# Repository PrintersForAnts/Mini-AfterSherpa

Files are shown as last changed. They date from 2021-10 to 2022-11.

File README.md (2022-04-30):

# Mini-AfterSherpa

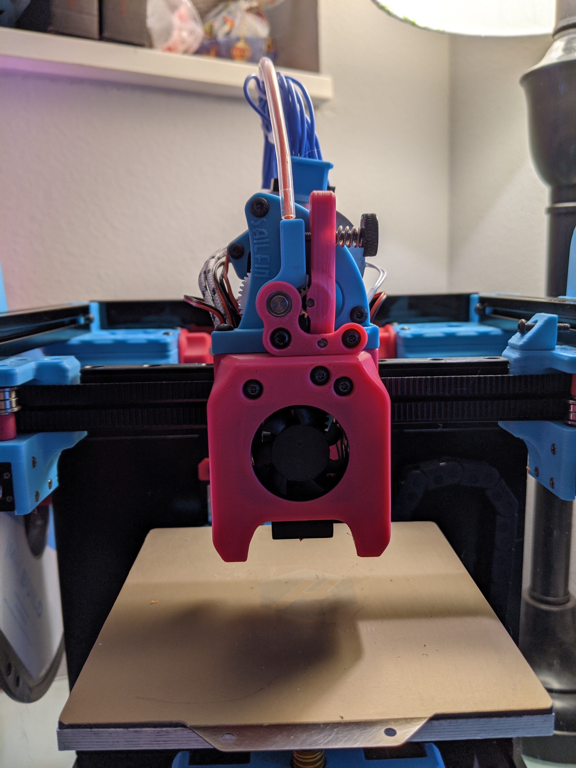
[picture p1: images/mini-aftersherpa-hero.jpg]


The Mini-AfterSherpa is an alternate toolhead for Voron V0.1 and similar printers ([Micron][micronURL], [Flying Zero][fzeroURL], [Salad Fork][saladForkURL], etc) that use the Mini-Afterburner-style X carriage. It offers flexibility and extruder choice with additional convenience.

[micronURL]: https://github.com/hartk1213/micron
[fzeroURL]: https://github.com/zruncho3d/f-zero
[saladForkURL]: https://github.com/YeriWyn/Salad_Fork

## Features

### Direct-drive extruders

With the Mini-AfterSherpa, you can choose from multiple direct-drive extruders.

- [Sherpa Mini](https://github.com/Annex-Engineering/Sherpa_Mini-Extruder)
- [Sherpa Micro](https://github.com/Annex-Engineering/Sherpa_Micro-Extruder) (Via untested adapter)
- [Sailfin](https://github.com/CroXY3D/Sailfin-Extruder)
- [Reverse Pocketwatch V2](STL/Reversed_PocketWatch2/Reversed_Pocketwatch2_Mini_AS_Edition_v0.593.zip), a modified version of the original [Pocketwatch V2](https://github.com/VoronDesign/Pocket-Watch)
- [Orbiter V1.5/V2.0](https://www.thingiverse.com/thing:4725897) (V1.5 supported, V2 TBD)
- [Jetpack](https://github.com/VoronDesign/Jetpack-Extruder) (coming soon, maybe someday)

### Bowden setups

Or, instead, [you can use a Bowden adapter][sherpaBowdenURL] to pair the Mini-AfterSherpa with any standard 1.75mm-filament Bowden extruder, including the [Voron M4][voronM4URL].

[sherpaBowdenURL]: https://github.com/KurioHonoo/Mini-AfterSherpa/tree/main/mods/LED-Bowden-Adapter
[voronM4URL]: https://github.com/VoronDesign/Mobius-Extruder/

### Hotends

- The Phaetus and TriangleLab Dragons and Phaetus Dragonfly BMO [share the same body][dragonflySTL].
- The groove-mount E3D V6 and _Zodiac_ Dragonfly BMO also [both share a main body][groovemountSTL], but you have to print the slide-in mount that goes with your hotend.
- The Slice Engineering Mosquito and Mellow NF Crazy [both share a main body](mosquitoSTL) as well.
- Support is _here_ for Zodiac and Phaetus Dragonfly BM**S**, as well as Revo Micro (and more…)

[dragonflySTL]: STL/Mini_AfterSherpa/Mini_AfterSherpa_Dragon(fly).stl
[groovemountSTL]: STL/Mini_AfterSherpa/Mini_AfterSherpa_Zodiac_BMO_Plus_V6_Body_x1.stl
[mosquitoSTL]: STL/Mini_AfterSherpa/Mini_AfterSherpa_Skeeter_x1.stl
[_insert_Revo Micro here_]
[_insert Revo Voron here_]
[_insert V6_Zodiac_BMO here_]

### Zip tie slots



The Mini-AfterSherpa includes two slots for zip ties to aid in cable management and strain relief. They're much easier to access and route cables through than the zip tie slots on the X carriage (and if you're using an aluminum X carriage like the one from Funssor, then it doesn't even _have_ any zip tie slots!)

## Assembly

### BOM

- 2×: M2.5×8mm BHCS/SHCS (to connect the hotend)
- 2×: M3×5×4mm heatset inserts (to connect the extruder or Bowden adapter)
- 3×: M3×35mm FHCS, BHCS, or SHCS
- 2×: 3010 blower fans (same as Mini-Afterburner)
- 1×: 3007 axial fan (same as Mini-Afterburner)

For Bowden setups:

- 1×: ECAS04 Bowden collet and clip
- 1×: 2mm innner diameter/4mm outer diameter PTFE tubing, 25mm long

### Instructions

1. Install both heatset inserts on the holes far to the sides of the top of the Mini-AfterSherpa.
1. Install fans following the instructions on [page 109 of the V0.1 manual](https://github.com/VoronDesign/Voron-0/raw/Voron0.1/Manuals/Assembly_Manual_0.1.pdf).
1. Install the hotend. 
  - For Dragon or Phaetus Dragonfly BMO, use the M2.5 bolts that came with the hotend. The following diagram will help determine which holes to use for your hotend.
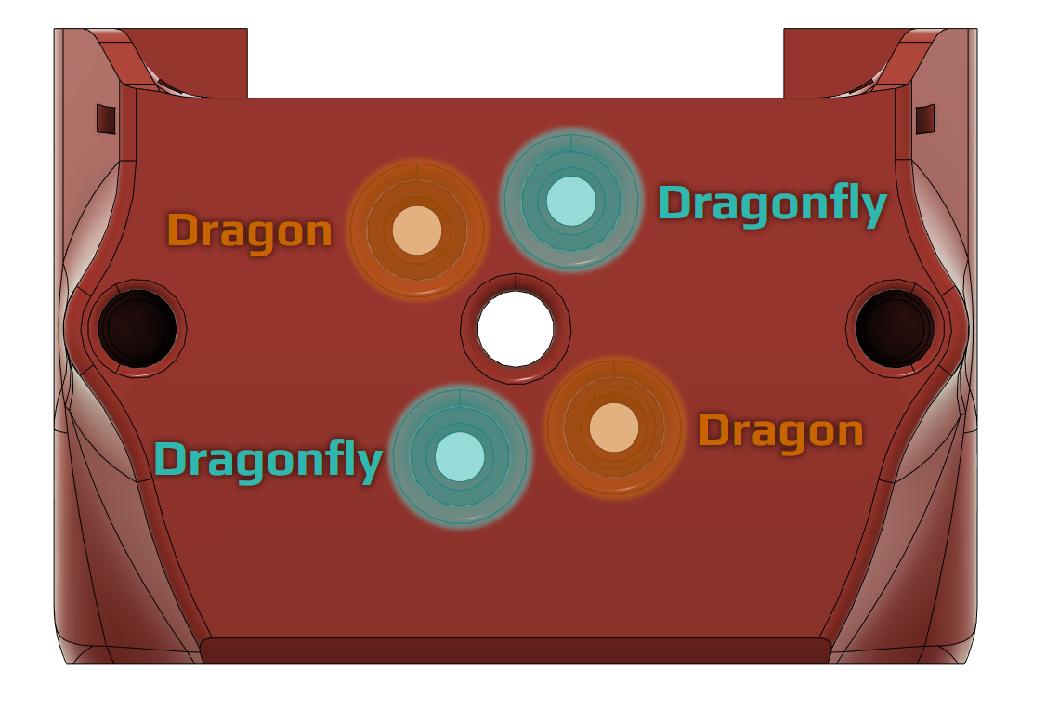
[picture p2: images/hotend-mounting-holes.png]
     
  - For the groove-mount V6 or the Zodiac Dragonfly BMO, slide the groove at the top of the heatsink into the main Mini-AfterSherpa body, then secure it in place by sliding the other mount part in behind the toolhead.
1. Attach the Mini-AfterSherpa to your X carriage with the M3×35mm bolts. Route the hotend wires to either side of the toolhead, and make sure not to crush them when you're tightening the M3 bolts.
1. Use zip ties to secure the wires on the sides of the Mini-AfterSherpa.   
   
1. Install your extruder or Bowden adapter.

## About

Made by [Kyrios](https://github.com/KurioHonoo), based on the [AfterSherpa by smolboi](https://www.thingiverse.com/thing:4977800).

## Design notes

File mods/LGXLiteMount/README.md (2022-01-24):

#LGX Lite Mount (beta) for V0.1 MiniAfterSherpa - Replaces MiniSherpa
MiniASLGXerpaLite.stl

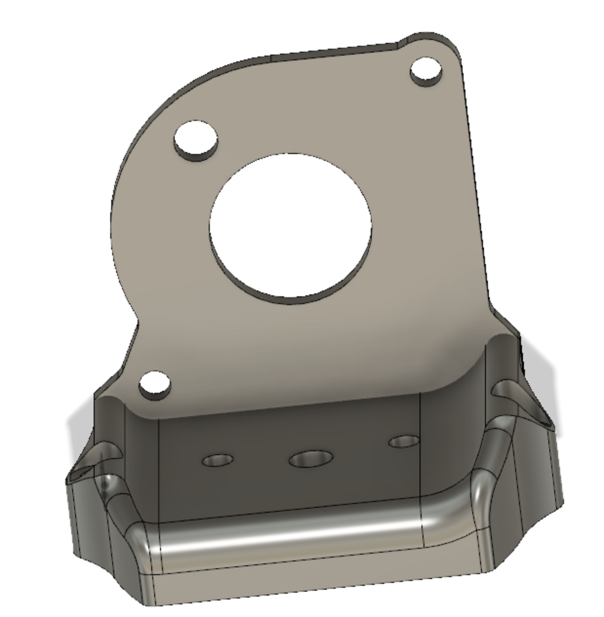
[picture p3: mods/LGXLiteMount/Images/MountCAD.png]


Use 2 x M3x8 from bottom up to secure LGX Lite to mount (Let me know if M3x10 would be better)
Use 2 x M3x12 from top down to secure mount to Mini-AfterSherpa https://github.com/KurioHonoo/Mini-AfterSherpa

Use PTFE tube (the include PTFE from LGX Lite is too short)

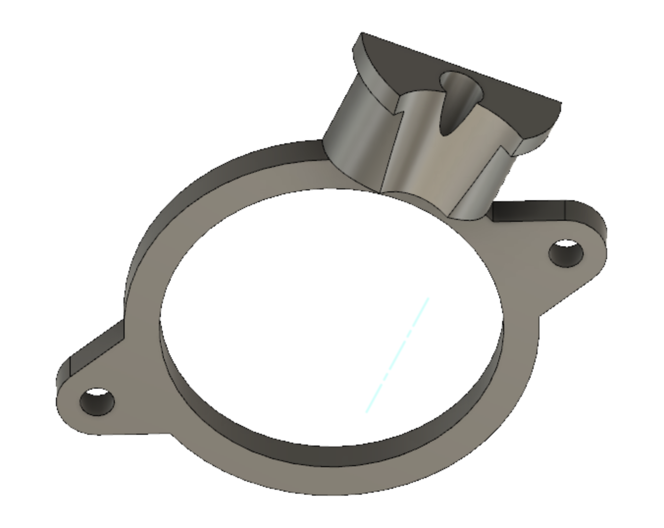
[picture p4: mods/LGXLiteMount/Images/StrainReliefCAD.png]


Strain Relief & Spacers
MiniASLGXerpaLite-StrainRelief.stl
Strain_Relief_Spacers_x2.stl

Use 2 x M3x30 (partially threaded preferred) to replace included M3x25
Optional Use Short piece of PTFE for added relief

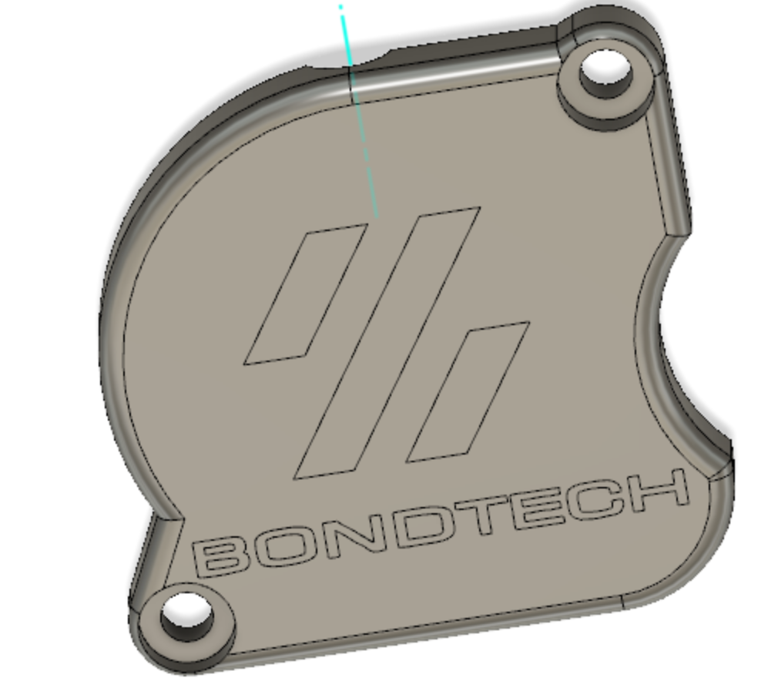
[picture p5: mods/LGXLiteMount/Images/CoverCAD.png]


LGX Lite Cover* - Bondtech requests that the logo be on the cover
MiniASLGXerpaLite-Cover.stl

*Tolerances are NOT exactly like the original cover.  Use at your own risk :D

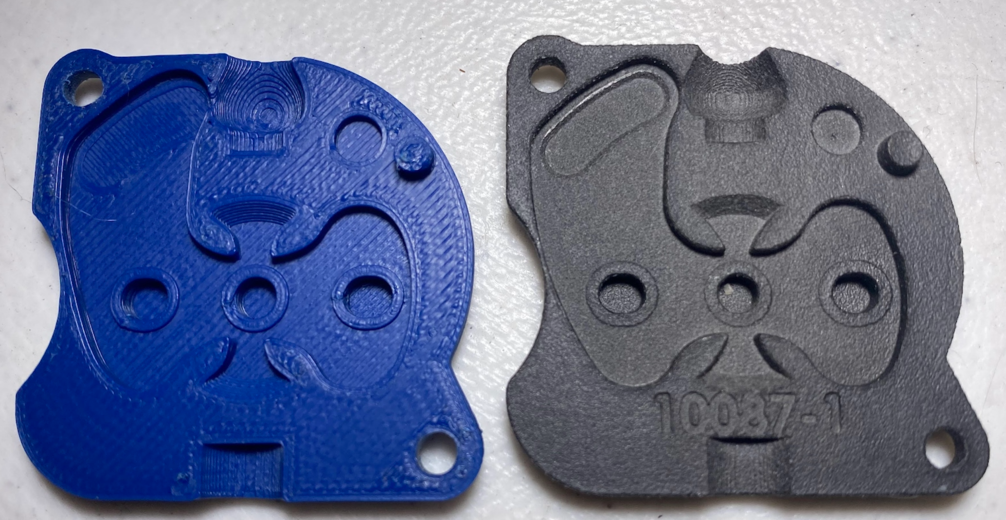
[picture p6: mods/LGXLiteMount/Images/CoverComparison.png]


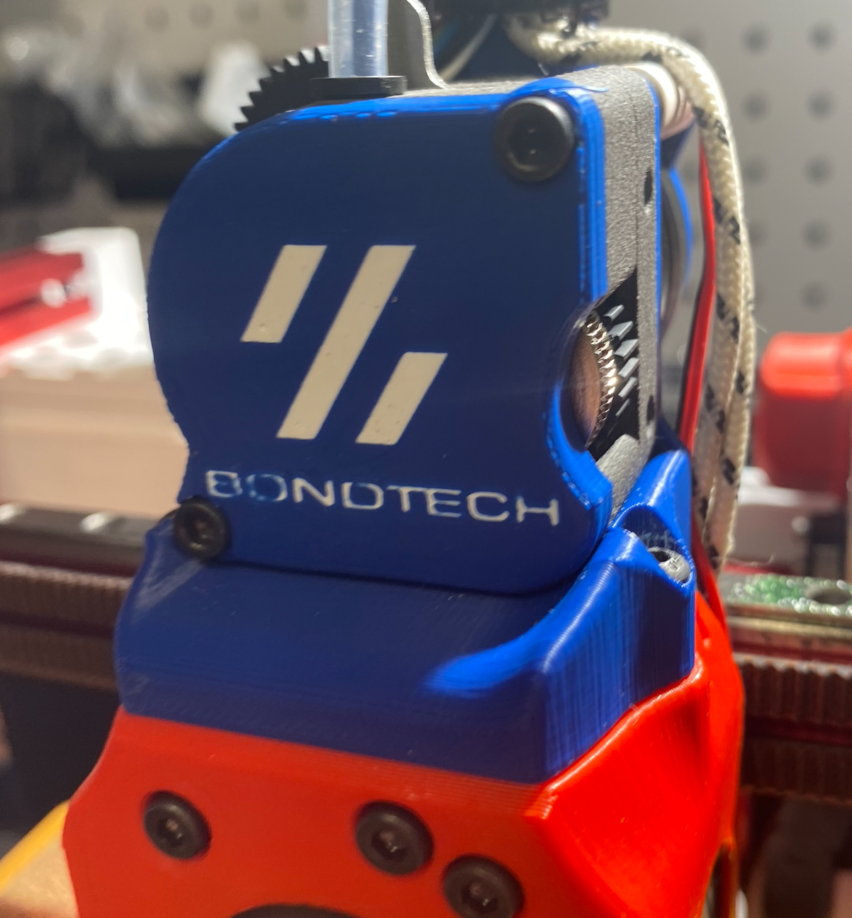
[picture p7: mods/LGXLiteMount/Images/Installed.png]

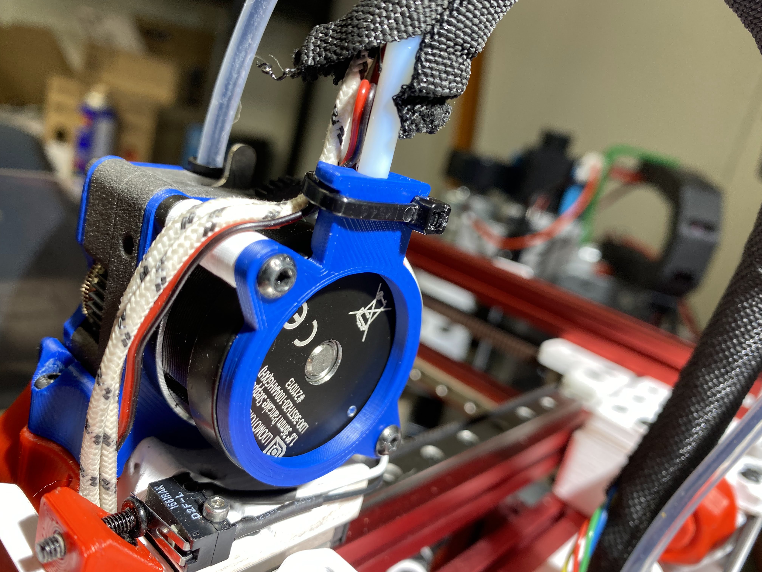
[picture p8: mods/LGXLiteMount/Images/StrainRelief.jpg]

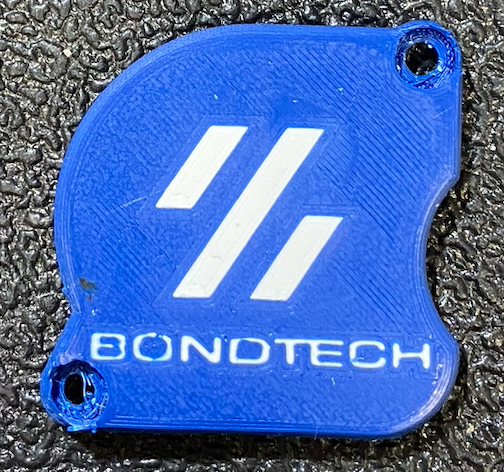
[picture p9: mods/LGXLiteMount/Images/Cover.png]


Contact me on Discord @cmrny with feedback.  Thanks

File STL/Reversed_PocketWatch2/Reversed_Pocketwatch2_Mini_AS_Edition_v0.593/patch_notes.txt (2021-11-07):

v0.593 - Switched all 3MF files to STL.

v0.592 - Added a missing chamfer to the back of Guts_rP2_back to the newly added top slot.

v0.591 - Added matching slots to the front of Motor_Mount_Front_rP2 and the back of Guts_rP2_back.

v0.590 - Properly named Latch_rP2 to [a]_Latch_rP2 as it is an accent color piece.

v0.589 - Initial release of the Reverse PocketWatch 2.

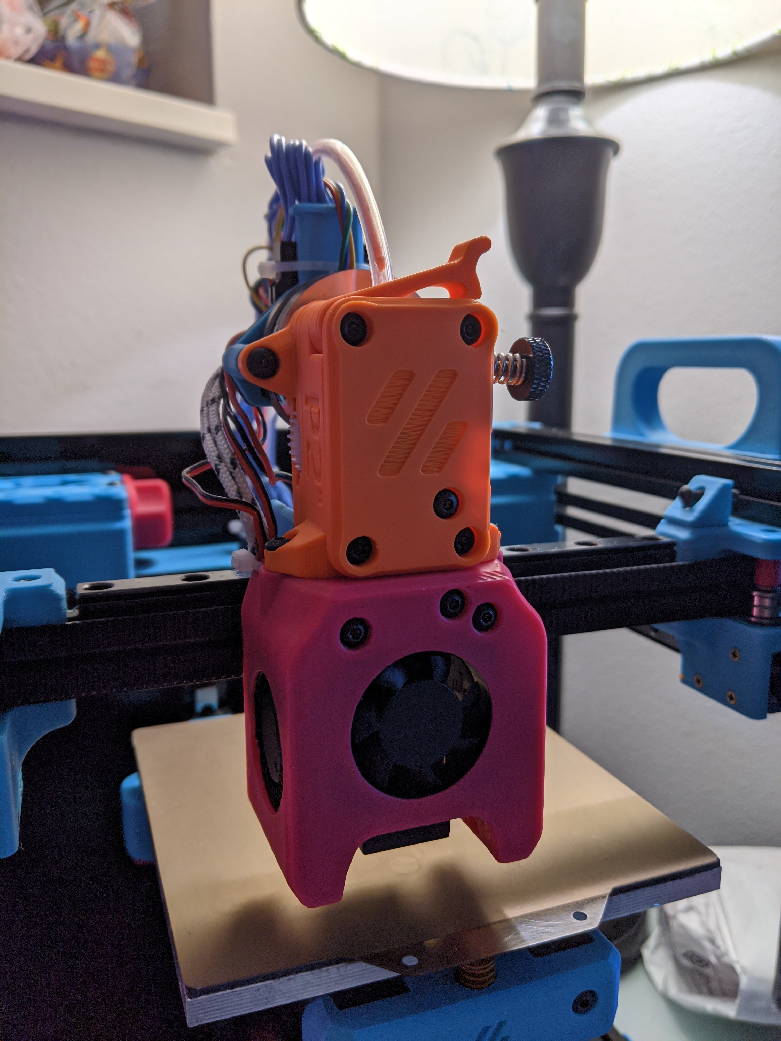
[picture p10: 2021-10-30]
images/Reversed_PW2_Mini_AS.jpg

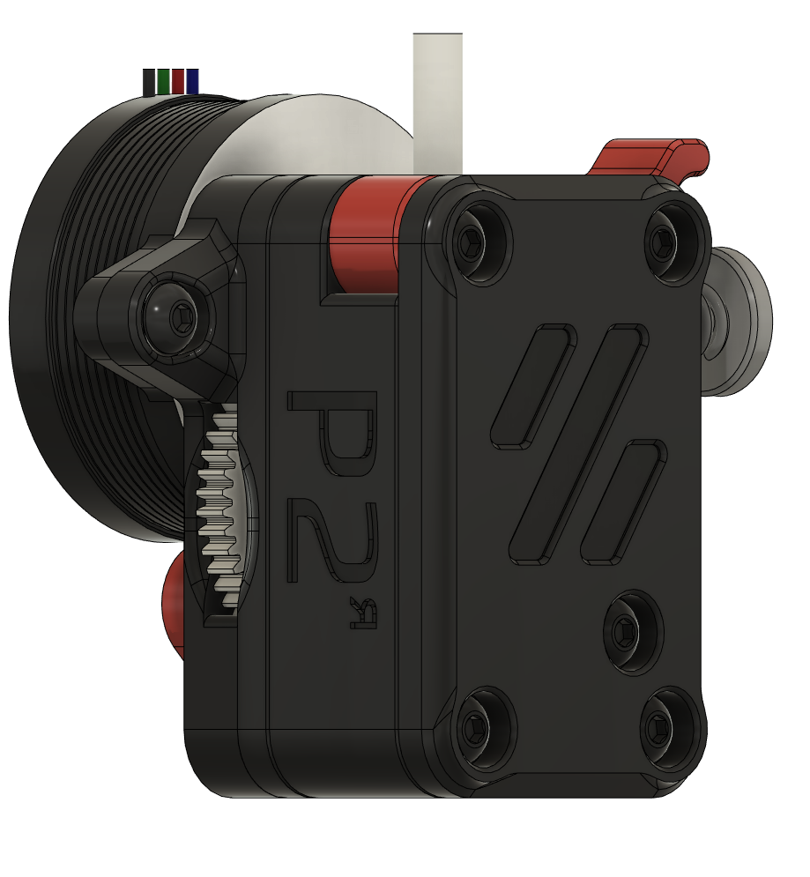
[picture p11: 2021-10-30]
images/rP2_front_left_deboss.png

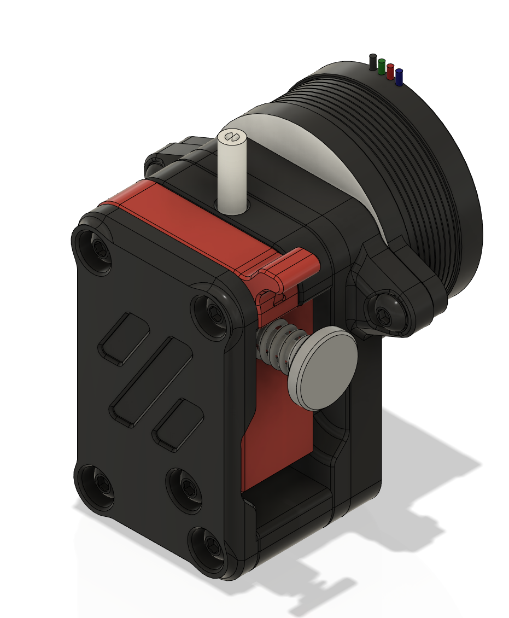
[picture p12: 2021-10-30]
images/rP2_face_right.png

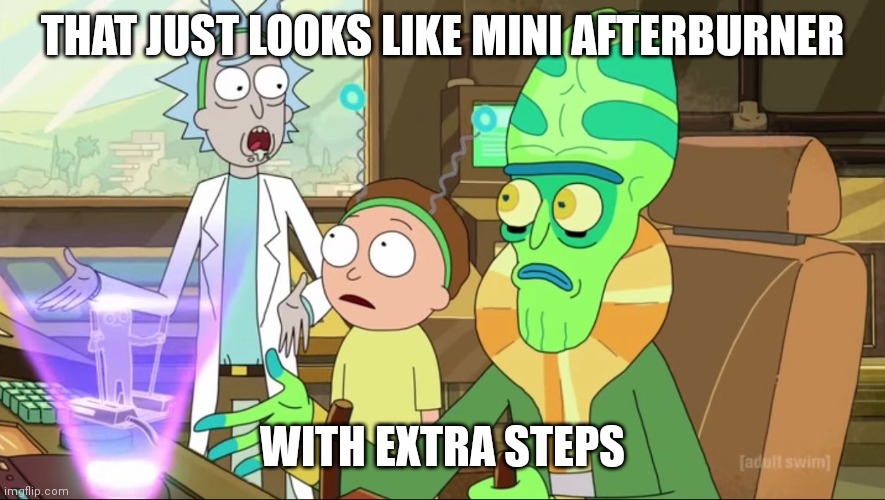
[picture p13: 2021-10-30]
images/rP2_MiniAB_Meme.jpg

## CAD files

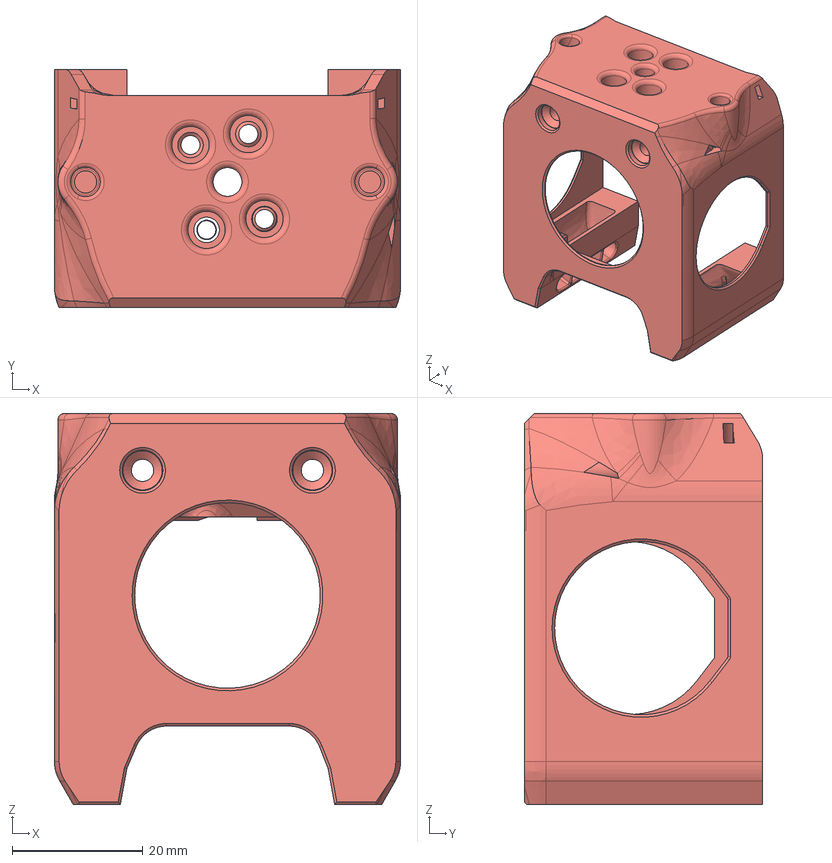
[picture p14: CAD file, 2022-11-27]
CAD/MiniAS_Dragon(fly)_Cowling.step
53.0 x 36.5 x 59.9 mm

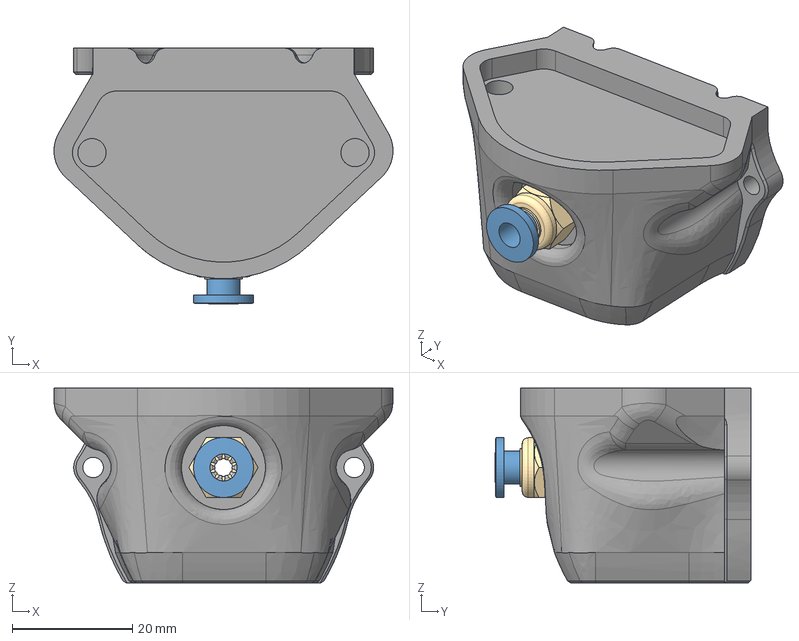
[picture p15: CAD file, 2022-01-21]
mods/LED-Bowden-Adapter/LED-Bowden.step
56.5 x 42.6 x 32.5 mm
M10-Bowden x 3
LED_Bowden_Toolhead
logo_led_carrier
rgbw_led_module
logo_led_diffuser

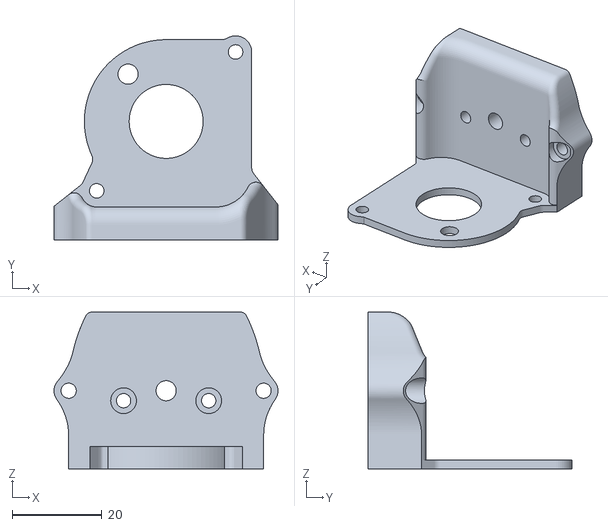
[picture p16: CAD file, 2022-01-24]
mods/LGXLiteMount/MiniASLGXerpaLite.stl
50.0 x 45.6 x 35.0

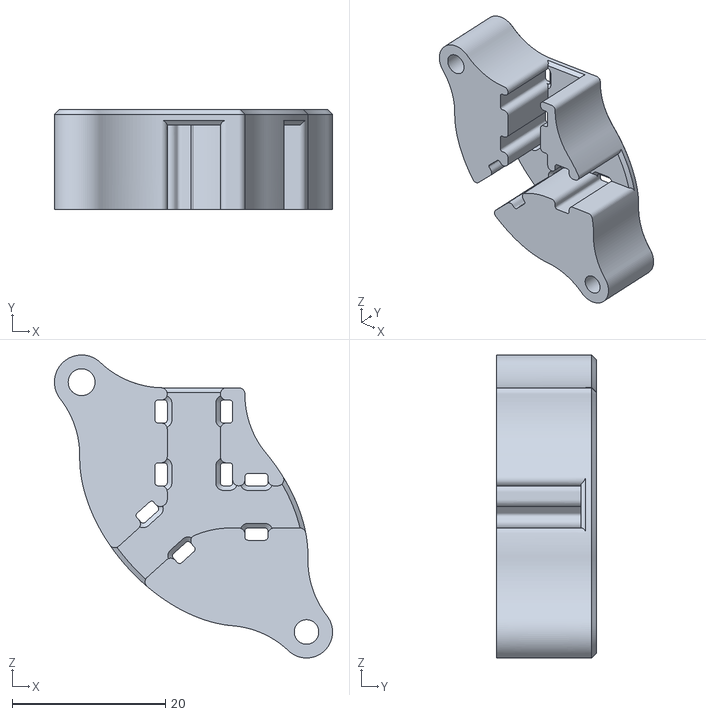
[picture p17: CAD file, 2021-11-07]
mods/Sailfin-strain-relief/Sailfin_Strain_Relief_x1.stl
36.3 x 13.0 x 39.5

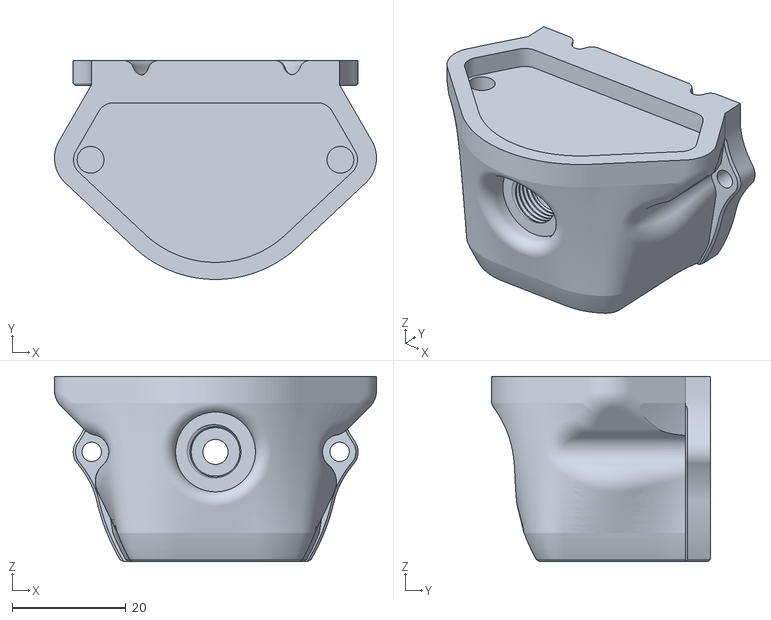
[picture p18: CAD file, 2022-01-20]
STL/LED-Bowden/bowden_toolhead.stl
56.5 x 38.4 x 32.5

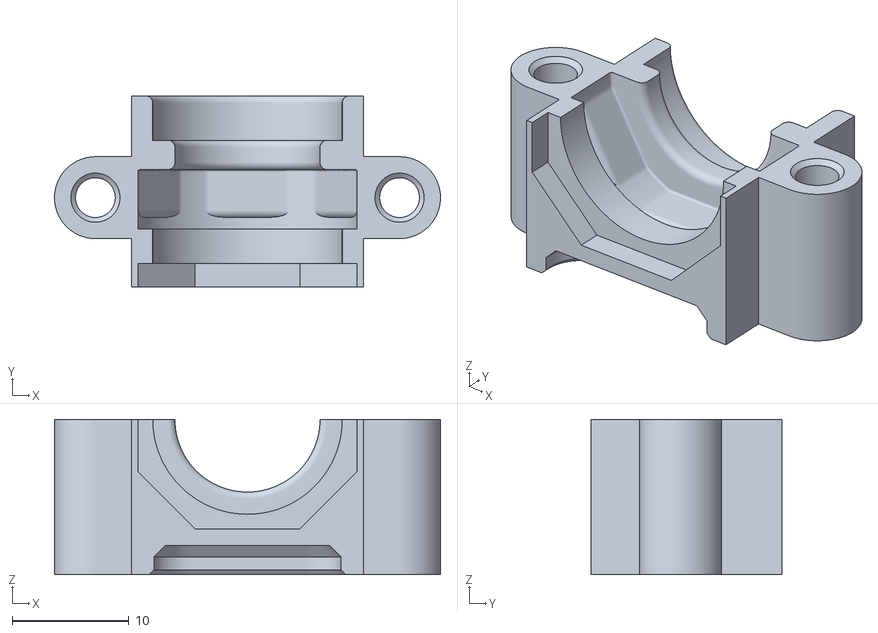
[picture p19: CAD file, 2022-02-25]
STL/Mini_AfterSherpa/E3D_Revo_Micro_Toolhead/MiniAS_Revo_Micro_Mount_V2_x1.stl
33.0 x 16.4 x 13.3

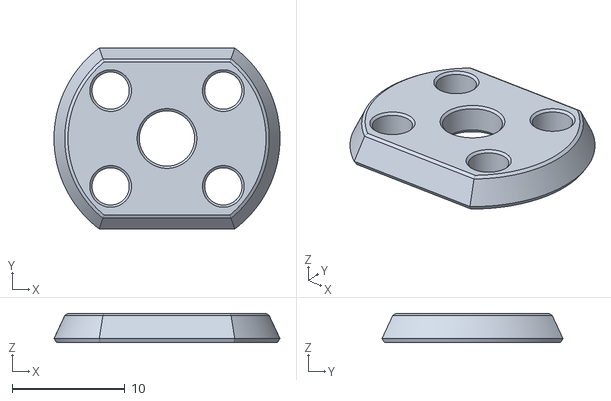
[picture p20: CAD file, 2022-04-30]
STL/Mini_AfterSherpa/E3D_Revo_Voron_Toolhead/MiniAS_RV_Hemera_Heatbreak_Shim.stl
20.1 x 16.1 x 2.60

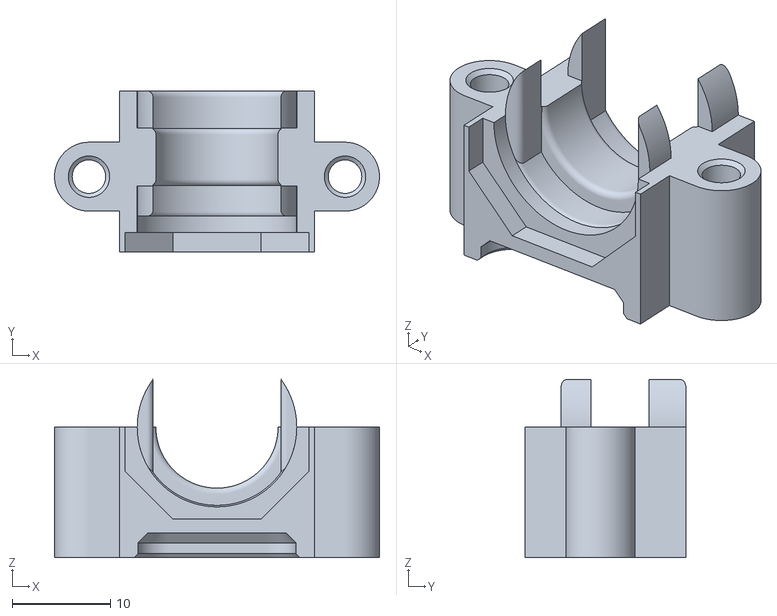
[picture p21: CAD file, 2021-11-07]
STL/Mini_AfterSherpa/E3D_V6_Zodiac_BMO_Toolhead/Mount_Zodiac_BMO_x1.stl
33.0 x 16.4 x 18.1

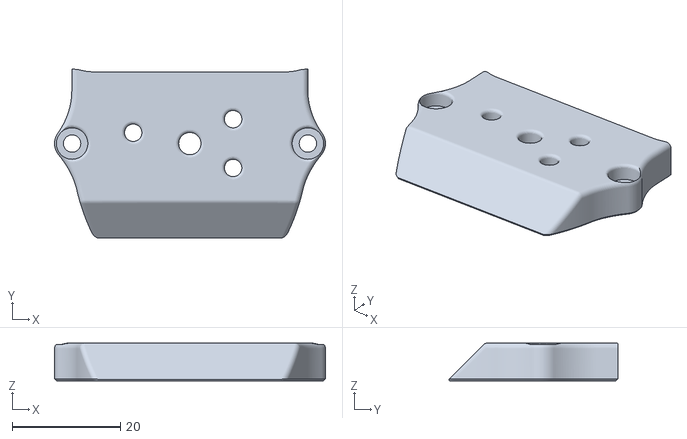
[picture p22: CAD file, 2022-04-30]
STL/Mini_AfterSherpa/Mini-AS_TBG-Lite_Mounting_Adapter.stl
50.0 x 31.3 x 7.00

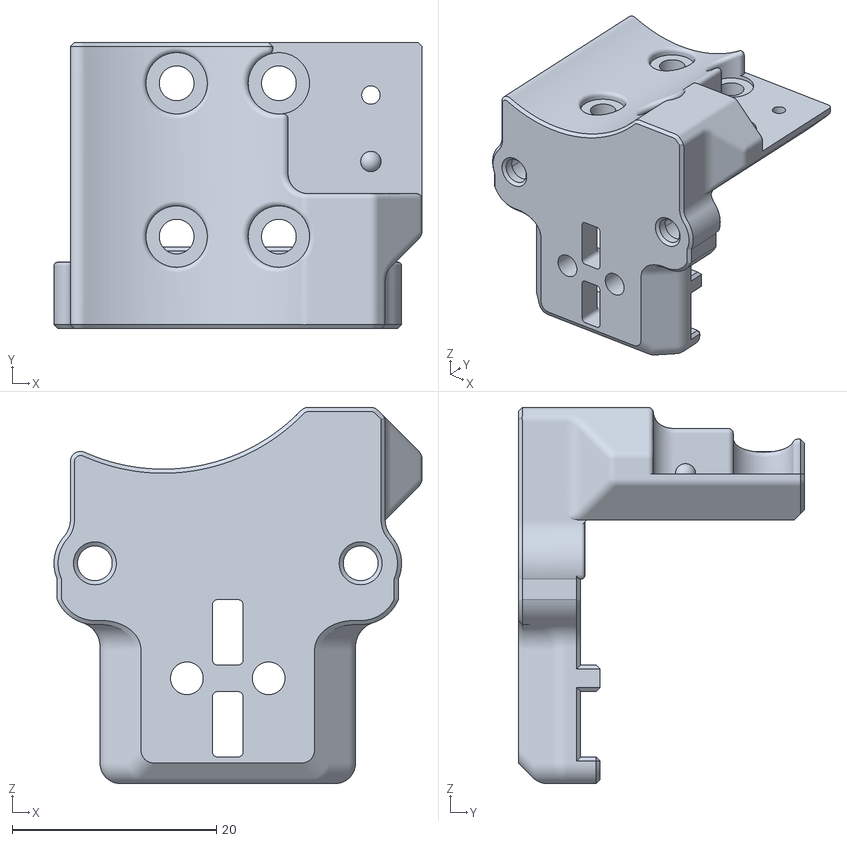
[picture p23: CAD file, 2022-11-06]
STL/Mini_AfterSherpa/Orbiter_V2_Toolhead_ONE-OFFS/Mini_AfterSherpa_Orbiter_v2_X_Carriage_MGN9C.stl
36.0 x 28.0 x 36.8

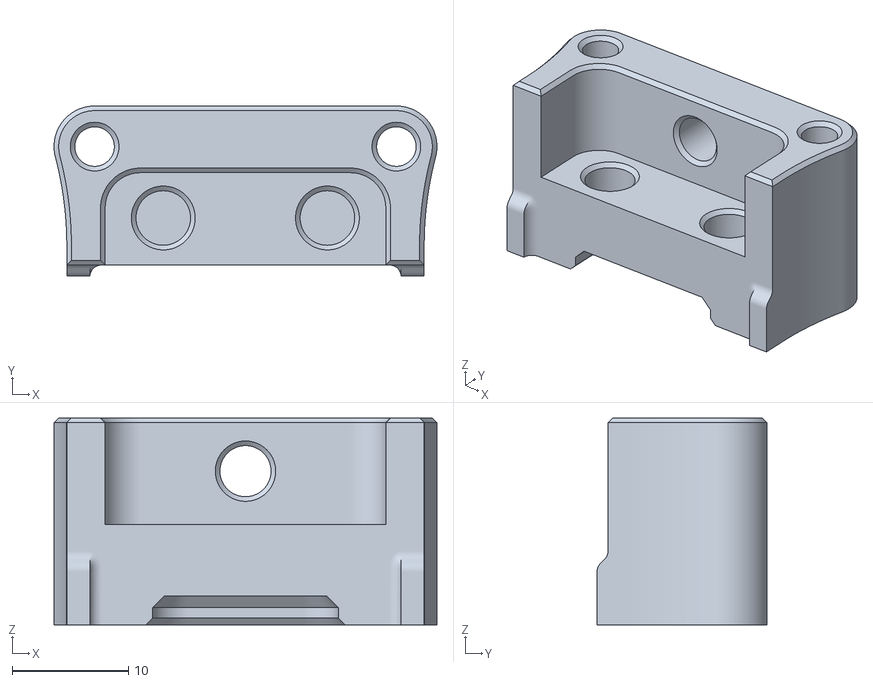
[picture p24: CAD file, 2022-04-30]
STL/Mini_AfterSherpa/Zodiac_BMS_Toolhead/Mini_AfterSherpa_Zodiac_BMS_Mount.stl
33.0 x 14.6 x 17.8

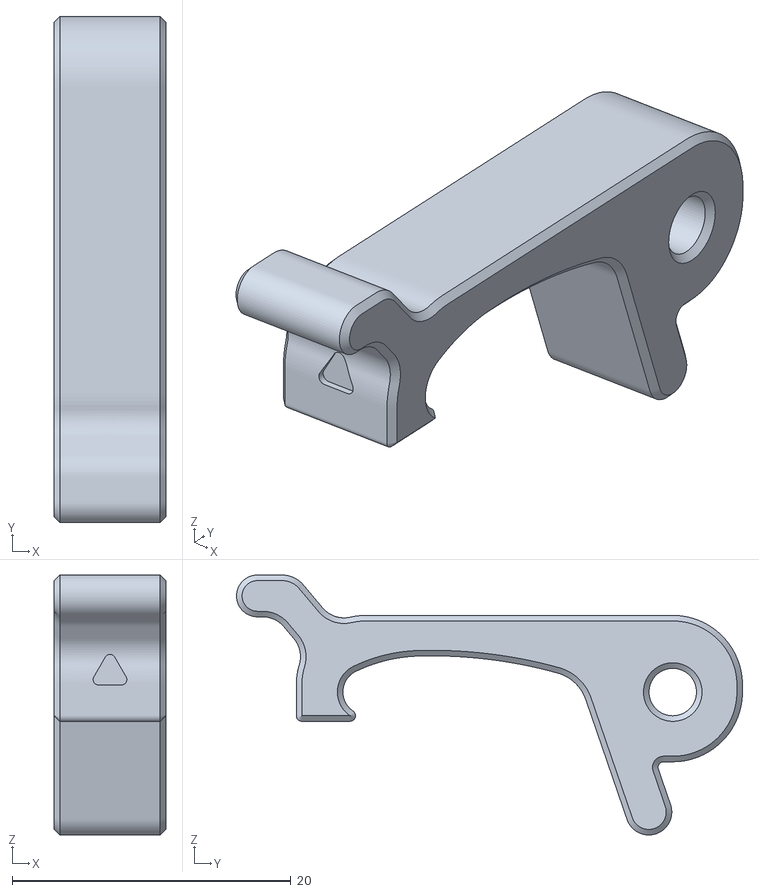
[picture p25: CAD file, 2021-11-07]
STL/Reversed_PocketWatch2/Reversed_Pocketwatch2_Mini_AS_Edition_v0.593/[a]_Latch_rP2_x1.stl
8.00 x 36.3 x 18.6

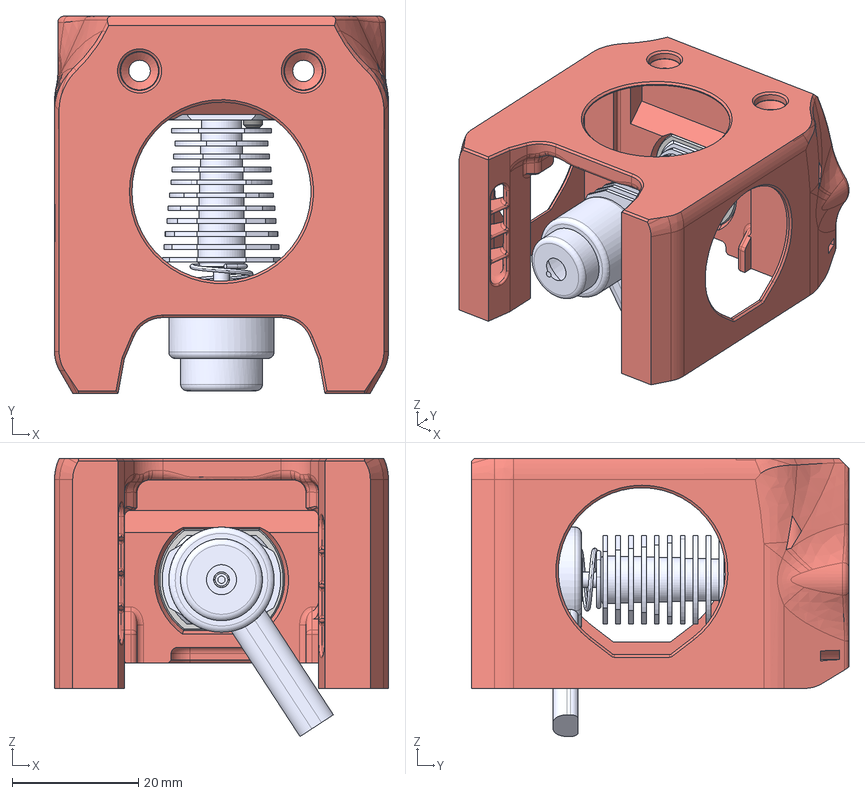
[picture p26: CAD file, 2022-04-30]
CAD/MiniAS_Revo_Voron_Base.step
53.0 x 61.9 x 44.1 mm
Revo_Voron_Reference_CAD
M3x8 BHCS

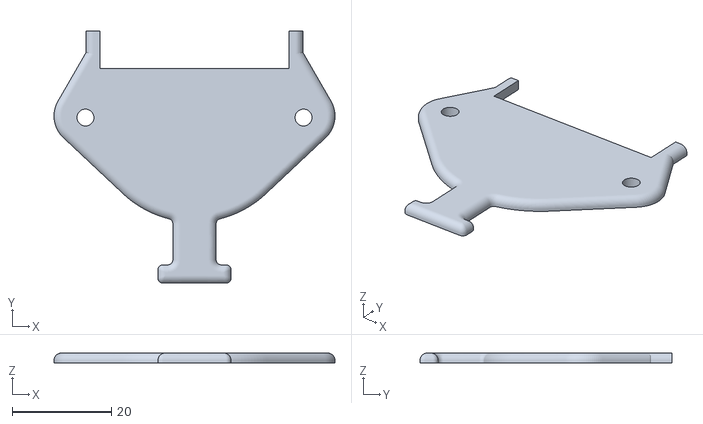
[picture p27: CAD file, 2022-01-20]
mods/LED-Bowden-Adapter/wire_cover.stl
56.5 x 50.7 x 2.00

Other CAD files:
STL/Mini_AfterSherpa/Orbiter_V2_Toolhead_ONE-OFFS/V6_Zodiac_BMO/Mini_AfterSherpa_Zodiac_BMO_Mount_x1.stl
mods/LGXLiteMount/Strain_Relief_Spacers_x2.stl
mods/Sailfin-strain-relief/sailfin-strain-relief.step
STL/Mini_AfterSherpa/E3D_Revo_Micro_Toolhead/MiniAS_Revo_Micro_Shim_V2_x1.stl
CAD/Mini-AfterSherpa_Zodiac_BMS.step
CAD/MiniAS_Orbiter_v1.5_Adapter v1.step
CAD/Mini_AfterSherpa_Orbiter_v2_X_Carriage.f3d
CAD/Mini_AfterSherpa_Orbiter_v2_X_Carriage_MGN9C.f3d
CAD/Mini_AfterSherpa_V6_Zodiac_BMO.step
STL/Mini_AfterSherpa/E3D_Revo_Micro_Toolhead/MiniAS_Revo_Micro_Faux_Collet_V2_X1.stl
STL/Mini_AfterSherpa/E3D_V6_Zodiac_BMO_Toolhead/Mount_E3D_V6_x1.stl
STL/Mini_AfterSherpa/MiniAS_Orbiter_v1.5_Adapter.stl
STL/Mini_AfterSherpa/MiniAS_Sherpa_Micro_Adapter.stl
STL/Mini_AfterSherpa/Orbiter_V2_Toolhead_ONE-OFFS/Mini_AfterSherpa_Orbiter_v2_X_Carriage.stl
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

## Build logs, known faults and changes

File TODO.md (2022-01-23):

#### Toolheads

- Dragon:
  - [x] Dragon(fly) Initial Release
- Groove-mount V6:
  - [x] Supported (not yet tested)
- Mosquito/NF Crazy:
  - [x] Supported. An alternative for the Voron 0.0 style toolhead mount is available from [smallboi here](https://www.thingiverse.com/thing:4977800)
- Threaded-mount V6/Revo?:
  - [ ] Not started yet, but supported by [smallboi's version](https://www.thingiverse.com/thing:4977800)

#### Extruders

 - Sherpa Mini:
   - [x] Supported (in theory)
   - [x] Verified (in practice)
 - Sailfin:
   - [x] Supported (in theory)
   - [x] Verified (in practice)
 - PocketWatch v2:
   - [x] Reverse P2 Initial Release
     - [x] Fix filament path thin wall
     - [ ] Improve current mounting points
       - [ ] Visually
       - [ ] Structurally
 - Orbiter:
   - [ ] Not started yet
  - Jet-Pack:
    - [ ] WIP/Planning

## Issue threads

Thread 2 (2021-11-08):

Counterbore too deep for rigid mounted Dragonfly BMO

maxkueng, 2021-11-08:
Hi! First, thanks for sharing this awesome design! I'm currently trying to get this to work with a Sherpa Mini and a Dragonfly BMO. While trying to mount the hotend I noticed that this doesn't work with the stock M2.5x8 bolts that come with the hotend.

The mounting holes of the Dragonfly aren't as deep as on the holes on the Dragon. They're only about 2.8mm deep going only through the first "floor" of the heatsink. So when trying to mount it, the screws can't be screwed all the way in. The counterbore on the Dragonfly holes is too deep.

The counterbore could be decreased by a few millimetres on the Dragonfly holes. However, on the version with with the guilder hole the guilder screw would then collide with the head of the mounting bolt because it now sits higher.

I've attached a section view that highlights the issue (the red part on the screw).

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

Here's what it would look like with 2.3mm less counterbore depth:

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

KurioHonoo, 2021-11-09:
This was fixed in eb823eb

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

Closed 2021-11-09.

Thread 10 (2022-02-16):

DRAGON Hotend PHAETUS Voron

rmilyard, 2022-02-16:
Do any of these cowling fit this hotend?

KurioHonoo, 2022-02-16:
The standard Dragon(fly) version will fit the Dragon Voron Edition.

rmilyard, 2022-02-16:
This one should fit then?

Mini-AfterSherpa/Cowling_Dragon(fly)_x1.stl at main · KurioHonoo/Mini-AfterSherpa (github.com)<https://github.com/KurioHonoo/Mini-AfterSherpa/blob/main/STL/Mini_AfterSherpa/Dragon(fly)_Toolhead/Cowling_Dragon(fly)_x1.stl>
________________________________
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

KurioHonoo, 2022-04-30:
Thought I replied to this. You're 1/4 genius though so you probably figured it out.

Closed 2022-04-30.

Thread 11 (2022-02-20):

E3D V6 Zodiac BMO Toolhead CAD missing

csch0, 2022-02-20:
Hi, I was quite happy when I saw you have that Hotends supported. I wanted to add support for https://github.com/zruncho3d/ZeroClick but unfortunatelly the CAD file does not include the support for that both hotends.

Could you update that?

rahulvij, 2022-03-11:
+1 on above, I want to mod the v6 version to fit a 4020 fan. Can you please share the CAD

KurioHonoo, 2022-04-30:
Only like 18 years late on this, sorry!! Added in https://github.com/KurioHonoo/Mini-AfterSherpa/commit/22ea37053a96fb3ac591a052a6c5b94502d981a9

Closed 2022-04-30.

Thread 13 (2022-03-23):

Support for Trianglelab TBG-Lite Extruder

Kozova1, 2022-03-23:
The TBG-Lite extruder is an alternative to the LGX lite extruder, with a slightly lower price and weight, and similar large drive gears.
I was wondering whether adding support for it to the Mini-AfterSherpa is possible and/or planned.
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

Trianglelab has released STEP files of the extruder which should help (can be found [here](https://drive.google.com/drive/folders/1Wax49gipz4rJb-TFV5nfNy9x6yN46WqA?usp=sharing)).
[Link to extruder](https://trianglelab.net/products/tbg-lite-extruder)

KurioHonoo, 2022-04-30:
DID IT https://github.com/KurioHonoo/Mini-AfterSherpa/commit/3c961951aaa136960b6f6fdd32643dab55ba0248

Closed 2022-04-30.

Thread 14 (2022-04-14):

Support for Orbiter V2 + Revo

failsafe-fpv, 2022-04-14:
Hey, this isn't an issue but I was just wondering if you've got a duct which supports an orbiter v2 and/or E3D Revo Voron hotend?

Cheers,

RC

KurioHonoo, 2022-04-14:
Oh god, I've neglected this repo severely.

Depending on which Revo model you have the standard size one works with any of the V6 style MiniAS models since the Revo is a drop in V6 replacement. I have a version for the Micro that I'm currently using on my V0, but it's unreleased. As for the Orbiter V2, I'll have to double check since I've made a fully custom cowling and x carriage for someone once as an example and I know that I've worked on a mounting plate adapter as well.

I have a tendency to make new versions and share them in my channel on DOOM or with clee and then I take forever to get it uploaded here.

KurioHonoo, 2022-04-14:
Reach out to me on Discord, I'm Kyrios on Voron and DOOM.

KurioHonoo, 2022-04-30:
Revo Voron support added with https://github.com/KurioHonoo/Mini-AfterSherpa/commit/22ea37053a96fb3ac591a052a6c5b94502d981a9

As for Orbiter V2 support.... oh hey, I think I hear my cat calling me.

failsafe-fpv, 2022-04-30:
Awesome, oh so there isn't an orbiter V2 mount available yet then?

KurioHonoo, 2022-05-07:
I currently have a the Dragon and a V6/Zodiac BMO version. Revo Voron will be an easy change though. I'm still not sure that I like so many different versions for this, but I guess it's really not that big of a deal.

jtrmal, 2022-05-07:
maybe that's how it is if you have so little space to work with :)

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

KurioHonoo, 2022-06-29:
Yeahhhhh sorry about the wait, but I did the thing. https://github.com/PrintersForAnts/Mini-AfterSherpa/commit/aa22476e9e41db300028ee4784a6ece3717b9866

jtrmal, 2022-06-29:
thanks!

Closed 2022-06-29.

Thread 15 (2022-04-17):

Support for Revo Voron

adadrag, 2022-04-17:
Since the Revo voron cold mount is out on market it will be very nice to have a mount for it.

KurioHonoo, 2022-04-18:
If you can find me a CAD/step file or even an STL of it then I can get right on it because I haven't been able to find anything. Otherwise I'm just going to have to wait until I get mine in and make the model myself.

Deathzo, 2022-04-25:
Will this work? I tried my cad-fu but uh yeah I'm lvl 0.01 with cad. Watching Solidworks videos though!

[](https://github.com/VoronDesign/Voron-0/blob/Voron0.1/STLs/Toolheads/Mini_Afterburner/Revo_Voron_Toolhead_DD/%5Ba%5D_Cowling_Revo_Voron_MULTIBODY_x1.STL)

KurioHonoo, 2022-04-30:
Added! https://github.com/KurioHonoo/Mini-AfterSherpa/commit/22ea37053a96fb3ac591a052a6c5b94502d981a9

Closed 2022-04-30.

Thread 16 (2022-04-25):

Request: `Cowling_Dragon(fly)_x1.stl` for the Sherpa-Micro

bassamanator, 2022-04-25:
I want to try the [Sherpa Micro](https://github.com/Annex-Engineering/Sherpa_Micro-Extruder) but it can't be mounted on the Mini-AfterSherpa.

Pretty please, with sugar on top?

KurioHonoo, 2022-04-30:
I created this a month ago and haven't had anyone to test it so lemme know. https://github.com/KurioHonoo/Mini-AfterSherpa/commit/22ea37053a96fb3ac591a052a6c5b94502d981a9

bassamanator, 2022-05-01:
Thanks for this! Will try it out are report my results.

Closed 2022-05-01.

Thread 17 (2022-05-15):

Support for TBG-Lite

mihuasdzxc, 2022-05-15:
Is it possible for us to get a cheaper toolhead for the dual gear extruder
(https://www.aliexpress.com/item/1005004186141062.html?spm=a2g0s.8937518.0.0.7bce2e0eNiz8Sc)
STEP link:https://drive.google.com/file/d/1v-6GjKYjTAMbKDbH-zMa1W4OttgJUjJe/view?usp=sharing

mihuasdzxc, 2022-05-15:
Ok I find it never mind

Closed 2022-05-15.

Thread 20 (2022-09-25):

Carriage for MG9 on X

chris155hp, 2022-09-25:
I’ve looked everywhere and no one has a carriage for that works with the Orbiter 2 and the hartk MGN9 on x Rail.  Any way we can make this happen?

arielja87, 2023-09-13:
Is it possible to get a STEP file for this as well? 🫶

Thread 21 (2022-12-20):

Added space for E3D V6 heatsink collet

NNGB-kor, 2022-12-20:
I use E3D V6 Bowden Heatsink and Orbiter v2.
Among the E3D V6 heatsinks, the 'Bowden' method has a collet.
If a heat sink for 'direct' use is used, the existing modeling is suitable.

I like the bimetal heatbreak.
some bimetal heatbreak products require a tube on top.
And it looks like you need a tube at the bottom of the Orbiter's filament guide.
So... the collet of the heatsink is an important existence.
The upper face of the body needs to protrude 3mm for the collet.
I personally tweaked the file you shared and found that a 3mm extrusion is the optimal height.

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

Please add a modified model for those who use a similar combination to me.

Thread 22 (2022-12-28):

Dragonfly Cowling

ZuurtjesGH, 2022-12-28:
The newly updated Dragonfly cowling does not with with the standard screws (standard screws are m2.5x6)
The counterbore holes are not deep enough.
The counterbore needs to be ±1.5-2mm deeper in order to fit it.

ZuurtjesGH, 2022-12-29:
Never mind user error
mistook the m2.5x6 screws used to mount it in the voron v0.1 as the standard screws, after rechecking the screws that are included with the dragonfly bmo should work

Closed 2022-12-29.

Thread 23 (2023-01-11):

CAD Model for Mini-AS_TBG-Lite_Mounting_Adapter

mjoconr, 2023-01-11:
Hi
I might be wrong but I do not think the CAD Model for [Mini-AS_TBG-Lite_Mounting_Adapter.stl](https://github.com/PrintersForAnts/Mini-AfterSherpa/blob/main/STL/Mini_AfterSherpa/Mini-AS_TBG-Lite_Mounting_Adapter.stl) has been uploaded
I would like to modify it to support the Hextrudort, this extruder uses the same bolt pattern but can not have the vertical plate.

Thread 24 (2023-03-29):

Sherpa micro (adapter) does not fit

Reisbauer1489, 2023-03-29:
The Sherpa micro adapter has a offset for the screws and filament path. Please test it before just uploading it to your github. Print out the sherpa micro housing_core  and test the fit. Please fix the stl.

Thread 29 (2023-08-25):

Support for Bambu hotend

robandwend, 2023-08-25:
Love this design. I'm currently converting a few of my printers to use the bambulabs hotend. Here's my design to fix a bambu on the mini-aftersherpa...

https://www.printables.com/model/562983-mini-aftersherpa-toolhead-design-for-bambulabs-hot.

Converted one Voron 0.1 so far - it's working well.

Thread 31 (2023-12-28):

Support for RGB NeoPixels

shkup, 2023-12-28:
Is it possible to add the orbiter v2 Voron REVO adapter RGB NeoPixels mounts?

https://github.com/PrintersForAnts/Mini-AfterSherpa/blob/main/STL/Mini_AfterSherpa/Orbiter_V2_Toolhead_ONE-OFFS/Revo_Voron/Mini_AS_Revo_Voron_Orbiter_V2.stl

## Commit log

2021-10-26 Initial revision
    [Mini_AfterSherpa_Dragon_Zip_Tie.3mf, Mini_AfterSherpa_Dragon_Zip_Tie_No_Guilder_Hole.3mf]
2021-10-26 Update hotend mounting hole image
2021-10-30 Initial release of rP2 and some restructuring
    [Guts_rP2_back_x1.3mf, Guts_rP2_front_x1.3mf, Mini_AfterSherpa_Dragon_Zip_Tie.3mf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]
2021-10-31 Trial version of Groove Mount V6 added. Renamed Dragon version to remove zip-tie mention.
    [Mini_AfterSherpa_Dragon.3mf, Mini_AfterSherpa_Dragon_No_Guilder_Hole.3mf, Mini_AfterSherpa_V6_Main_Body.3mf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]
2021-11-06 Unified the V6 Groove mount and Zodiac BMO body, created a separate mount for each.
    [Mini_AfterSherpa_V6_Main_Body.3mf, Mini_AfterSherpa_V6_Mount.3mf, Mini_AfterSherpa_V6_Mount_x1.3mf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]
2021-11-06 Fixed a whoopsie with the Zodiac BMO mount.
    [Mini_AfterSherpa_Zodiac_BMO_Mount_x1.3mf]
2021-11-07 Add wire organizer for use with Sailfin extruder.
    [sailfin-strain-relief.f3d, sailfin-strain-relief.step, sailfin-strain-relief.stl]
2021-11-07 Replaced all 3MF files with STL. Added 0.4mm chamfers to the screw holes on Fwiffo's strain relief because I'm a lunatic. Thank you, goodnight.
    [Guts_rP2_back_x1.3mf, Guts_rP2_back_x1.stl, Guts_rP2_front_x1.3mf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]
2021-11-09 Increased the screw path length for the Dragonfly BMO. They were previously the same depth as the Dragon which was too short for the M2.5x8mm screws that come with the Dragonfly BMO.
2021-11-09 Renamed the stl files to to make it obvious that the body caters to both.
2021-12-06 Beta support for Orbiter V2
    [Mini_AfterSherpa_OrbiterV2_X_Carriage.stl, Mini_AfterSherpa_Orbiter_v2_X_Carriage.f3d]
2021-12-14 Initial Mosquito support
    [Mini_AfterSherpa_Skeeter_No_Guilder_Hole_x1.stl, Mini_AfterSherpa_Skeeter_x1.stl]
2022-01-20 Add hartk's new Bowden adapter
    [LED-Bowden.step, bowden_toolhead.stl, led_logo_diffuser.stl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]
2022-01-21 Fix hartk's new Bowden adapter
    PCB fit was too tight. Pushed out walls around PCB by 0.5mm, and
    now the toolhead PCB fits properly without any friction.
    [LED-Bowden.step]
2022-01-23 Attempt at restructuring and renaming files and directories for clarity (#4)
    * Initial Mosquito support
    * Initial file renaming
    [Carriage_Orbiter_V2_X_x1.stl, Cowling_Mosquito_No_Guilder_Hole_x1.stl, Cowling_Mosquito_x1.stl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]
2022-01-23 Add mods folder, reorganize mods
    [Cowling_Mosquito_No_Guidler_Hole_x1.stl, LED-Bowden.step, Sailfin_Strain_Relief_x1.stl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]
2022-01-24 Add LGX Lite Mount (#8)
    * Update .gitignore
    * Added LGX Lite Mount for MiniAS
    * Update README.md
    [MiniASLGXerpaLite-Cover.stl, MiniASLGXerpaLite-StrainRelief.stl, MiniASLGXerpaLite.stl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]
2022-02-23 Fix hole depth for dragonfly (#9)
    * Fix hole depth for dragonfly
    * Add cable support for orbiter v2.0
    [Orbiter v2.0 cable support.stl]
2022-02-25 Added E3D Revo Micro Toolhead STEP and STL files.
    MiniAS_Revo_Micro_Faux_Collet and MiniAS_Revo_Micro_Shim are technically option, but very much recommended.
    [MiniAS_Revo_Micro_Faux_Collet_V2_X1.stl, MiniAS_Revo_Micro_Mount_V2_x1.stl, MiniAS_Revo_Micro_Shim_V2_x1.stl]
2022-02-27 Added Orbiter V1.5 Adapter from L3LK3K#4470
    L3LK3K#4470 Was kind enough to share his V1.5 adapter STEP file.
    [MiniAS_Orbiter_v1.5_Adapter v1.step, MiniAS_Orbiter_v1.5_Adapter.stl]
2022-04-16 Fix orientation for cowlings
    [Carriage_Orbiter_V2_X_x1.stl, Cowling_Mosquito_No_Guidler_Hole_x1.stl, Cowling_Mosquito_x1.stl]
2022-04-30 Added Revo Voron support, Sherpa Micro adapater, and missing CAD files
    Added Revo Voron support as well as support for the Revo Voron heatsink with a Hemera heatbreak and standard heatblock via a small 2.6mm shim. Added a Sherpa Micro adapter that hasn't been tested, someone gimme feedback. Finally included the V6/Zodiac BMO CAD files.
    [MiniAS_RV_Hemera_Heatbreak_Shim.stl, MiniAS_Revo_Voron_Base.step, MiniAS_Sherpa_Micro_Adapter.stl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]
2022-04-30 Fixed New STL Orientation
    Some idiot forgot to do it.
    [MiniAS_RV_Hemera_Heatbreak_Shim.stl, MiniAS_Sherpa_Micro_Adapter.stl]
2022-04-30 BUNCHA MISSING STUFF
    Added missing Zodiac BMS STL and STEP. Added Orbiter V2 V6/Zodiac BMO and Dragon(fly) STEP and STL files. WARNING!! THE ORBITER V2 FILES REQUIRE USING THE INCLUDED X CARRIAGE.
    [Carriage_Orbiter_V2_X_x1.stl, Mini-AfterSherpa_Zodiac_BMS.step, Mini_AfterSherpa_Orbiter_v2_X_Carriage.stl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]
2022-04-30 Fixed mounting holes for Revo Voron Cowling
    Screws weren't recessed.
    [MiniAS_Revo_Voron_Base.step]
2022-11-06 Orbiter V2 MGN9C Carriage
    [Mini_AfterSherpa_Orbiter_v2_X_Carriage_MGN9C.f3d, Mini_AfterSherpa_Orbiter_v2_X_Carriage_MGN9C.stl]
2022-11-27 Doing some Dragon(fly) cleanup and updating the Mosquito Cowling
    [Cowling_Mosquito_No_Guidler_Hole_x1.stl, Cowling_Mosquito_x1.stl, MiniAS_Dragon(fly)_Cowling.step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]
